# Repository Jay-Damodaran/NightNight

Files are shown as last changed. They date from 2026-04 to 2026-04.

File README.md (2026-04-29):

# NightNight
BME 349 Instrumentation Project - Automatic Light Switch System

NightNight is a portable, convenient attachment for existing light panels that shuts off the lights at a configured time. This was designed for tired college students who have a habit of dosing off with the lights still on, but it can be used by anyone that wants their lights to turn off automatically. The beauty of this product is that it saves you the hassle of modifying an existing light panel and having to make all the electrical connections. It sits over existing panels and can be removed and placed over any other panel! 

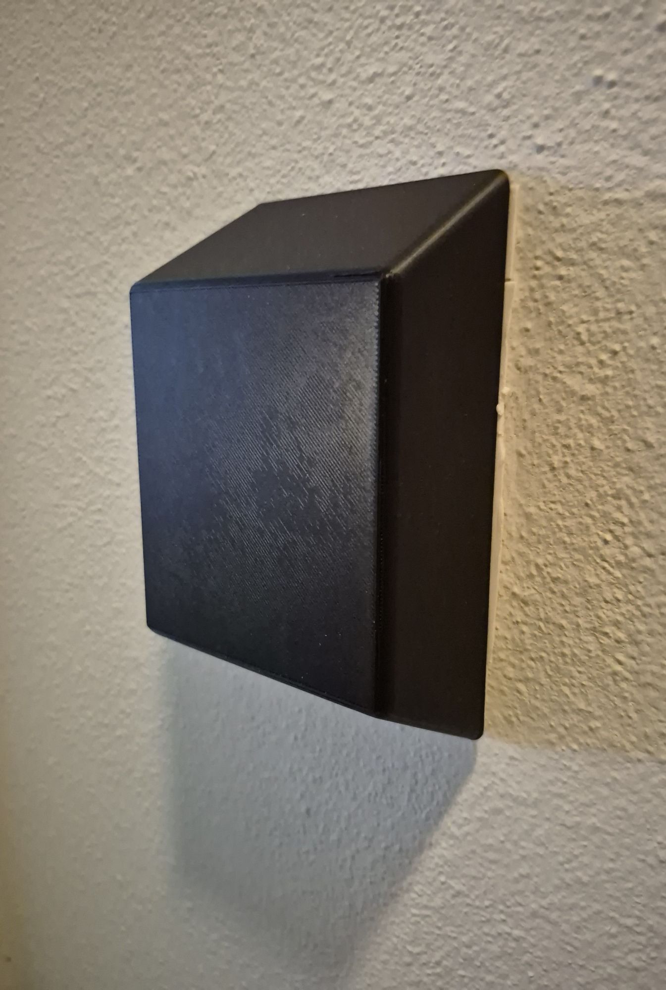
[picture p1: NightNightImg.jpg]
NightNight Image


## Demo

https://github.com/user-attachments/assets/0a69e3f3-7d46-4c19-8ec1-e0d74f1d1b15

## Repo Contents
- **NightNightCircuit** — KiCAD circuit schematic for the NightNight module
- **nightNightMain** — firmware running on the XIAO ESP32-C3
- **testSuite** — test scripts for different components of the module
- **flowchart.svg** — detailed system flow diagram

Simplified Module Flow Diagram
NightNight Flow

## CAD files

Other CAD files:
NightNightCAD/261L Project Housing.f3d

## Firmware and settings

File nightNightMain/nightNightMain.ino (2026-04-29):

// NightNight Automatic Lights off firmware for XIAO ESP32-C3 MCU
// Wakes at 12 AM via DS3231, extends then retracts servo
// BATTLOW: flash red LED every 10 min using light sleep
// BATTHIGH: hold green LED on via RTC GPIO through deep sleep when device is fully charged
// Wiring shown in KiCAD schematic

#include <RTClib.h>
#include <ESP32Servo.h>
#include "esp_sleep.h"
#include "driver/gpio.h"
#include "WiFi.h"
#include "esp_bt.h"

// gpio pin definitions
#define RTC_INT_PIN 3
#define SERVO_PIN D3
#define BATTERY_PIN A0
#define GLED_PIN D8
#define RLED_PIN D2

// actuator timing macros for extension and retraction
#define EXTEND_DELAY_MS 800
#define RETRACT_DELAY_MS 800

// 3.265V real / 2 (divider) = 1632.5mV
#define BATT_LOW_MV 1633
#define BATT_FULL_MV 2050

// macros defining low battery led flash timing
#define FLASH_ON_US 400000ULL
#define FLASH_OFF_US 600000ULL
#define FLASH_CYCLES 120
#define SLEEP_8MIN_US 480000000ULL

// 12 AM alarm 
#define ALARM_HOUR 0
#define ALARM_MINUTE 0
#define ALARM_SECOND 0

// define rtc and servo/actuator
RTC_DS3231 rtc;
Servo actuatorServo;

// enum for tracking battery level
enum BatteryLvls { BATTLOW, BATTMED, BATTHIGH };

// function prototypes for all functions used
void disableUnusedPeripherals();
void initRTC();
void setNextAlarm();
void clearAlarmFlag();
void runActuatorTask();
uint8_t batteryLevel();
void enterDeepSleep();
void lightSleepUs(uint64_t us);
void runBatteryLoop();

// Runs on every boot and every deep sleep wake
void setup() {
    // shuf off wifi and bluetooth
    disableUnusedPeripherals();
    // configure RTC
    initRTC();

    // configure led pins, turn off, and stop any holds that could have persisted through deep sleep
    pinMode(RLED_PIN, OUTPUT);
    digitalWrite(RLED_PIN, LOW);
    gpio_deep_sleep_hold_dis();
    gpio_hold_dis((gpio_num_t)GLED_PIN);
    pinMode(GLED_PIN, OUTPUT);
    digitalWrite(GLED_PIN, LOW);

    esp_sleep_wakeup_cause_t cause = esp_sleep_get_wakeup_cause();

    // go back to sleep if wake didn't happend from RTC interrupt
    if (cause != ESP_SLEEP_WAKEUP_EXT0) {
        setNextAlarm();
        enterDeepSleep();
        return;
    }

    // acknowledge alarm
    clearAlarmFlag();
    // extend and retract actuator to turn off light switch
    runActuatorTask();
    // assess battery level and flash red led if battery low and turn on green if battery ful
    runBatteryLoop();
    // set RTC alarm based on the alarm timing macros
    setNextAlarm();
    // hold green led on through deep sleep if battery level is high, so user can uplug device
    if (batteryLevel() == BATTHIGH) {
        gpio_hold_en((gpio_num_t)GLED_PIN);
        gpio_deep_sleep_hold_en();
    }
    // deep sleep for power conservation
    enterDeepSleep();
}

void loop() {}

void disableUnusedPeripherals() {
    WiFi.mode(WIFI_OFF);
    btStop();
    esp_bt_controller_disable();
}

void initRTC() {
    if (!rtc.begin()) {
        while (true) { delay(1000); }
    }
    if (rtc.lostPower()) {
        rtc.adjust(DateTime(F(__DATE__), F(__TIME__)));
    }
    rtc.disable32K(); // pin not used
    rtc.clearAlarm(1);
    rtc.clearAlarm(2);
    rtc.writeSqwPinMode(DS3231_OFF); // required before setAlarm1 to stop oscillations in this line
    rtc.disableAlarm(2);
}

void setNextAlarm() {
    DateTime now = rtc.now();
    DateTime next = DateTime(
        now.year(), now.month(), now.day(),
        ALARM_HOUR, ALARM_MINUTE, ALARM_SECOND
    );
    if (now >= next) { // set alarm for next day if time has already passed
        next = next + TimeSpan(1, 0, 0, 0); 
    }
    rtc.setAlarm1(next, DS3231_A1_Hour); 
}

void clearAlarmFlag() {
    rtc.clearAlarm(1);
}

// extend and retract servo
void runActuatorTask() {
    actuatorServo.attach(SERVO_PIN);
    delay(200);
    actuatorServo.write(180);
    delay(EXTEND_DELAY_MS);
    actuatorServo.write(0);
    delay(RETRACT_DELAY_MS);
    actuatorServo.detach();
}

// battery level gauged from average of 5 samples read from voltage divider connected to A0
uint8_t batteryLevel() {
    uint32_t mv = 0;
    for (uint8_t i = 0; i < 5; i++) {
        mv += analogReadMilliVolts(BATTERY_PIN);
    }
    mv /= 5;
    if (mv < BATT_LOW_MV) {
        return BATTLOW;
    }
    if (mv >= BATT_FULL_MV) {
        return BATTHIGH;
    }
    return BATTMED;
}

void enterDeepSleep() {
    esp_deep_sleep_enable_gpio_wakeup(1ULL << RTC_INT_PIN, ESP_GPIO_WAKEUP_GPIO_LOW);
    esp_deep_sleep_start();
}

void lightSleepUs(uint64_t us) {
    esp_sleep_enable_timer_wakeup(us);
    esp_light_sleep_start();
}

// 10-min cycle: flash red LED for 2 min, light sleep 8 min
// turn on green led if battery level is high
void runBatteryLoop() {
    while (batteryLevel() == BATTLOW) {
        // each cycle is 1s, so 120 loop iterations to reach 2 min
        for (int cycle = 0; cycle < FLASH_CYCLES; cycle++) {
            digitalWrite(RLED_PIN, HIGH);
            lightSleepUs(FLASH_ON_US);
            digitalWrite(RLED_PIN, LOW);
            lightSleepUs(FLASH_OFF_US);
        }
        lightSleepUs(SLEEP_8MIN_US);
    }
    if (batteryLevel() == BATTHIGH) {
        digitalWrite(GLED_PIN, HIGH);
    }
}

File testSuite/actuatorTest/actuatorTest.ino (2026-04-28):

// Servo actuator test — XIAO ESP32-C3
// Extend then retract once on boot. Repeats every 5 seconds.
// GPIO5 — Servo PWM

#include <ESP32Servo.h>

#define SERVO_PIN        D3
#define EXTEND_DELAY_MS  800
#define RETRACT_DELAY_MS 800

Servo actuatorServo;

void setup() {
    Serial.begin(9600);
    delay(1000);
    Serial.println("Servo test starting");
}

void loop() {
    Serial.println("Extending...");
    actuatorServo.attach(SERVO_PIN);
    delay(200);
    actuatorServo.write(180);
    delay(EXTEND_DELAY_MS);

    Serial.println("Retracting...");
    actuatorServo.write(0);
    delay(RETRACT_DELAY_MS);

    actuatorServo.detach();
    Serial.println("Done. Waiting 5s...");
    delay(5000);
}

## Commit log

2026-04-21 Added NightNight circuit and code
    [NightNightCircuit.kicad_pcb, NightNightCircuit.kicad_sch]
2026-04-28 Updated battery level monitoring to not run indefinitely
2026-04-28 Added green led on feature when battery fully charged
2026-04-28 Fixed rtc-actuator test, circuit diagram, and main code
    [NightNightCircuit.kicad_sch]
2026-04-28 Updated to RTC interrupt in test and added additional setup to initRTC in main script
2026-04-29 Added system flow diagrams and simplified main script comments
2026-07-15 Added housing Fusion360 file
    [261L Project Housing.f3d]
